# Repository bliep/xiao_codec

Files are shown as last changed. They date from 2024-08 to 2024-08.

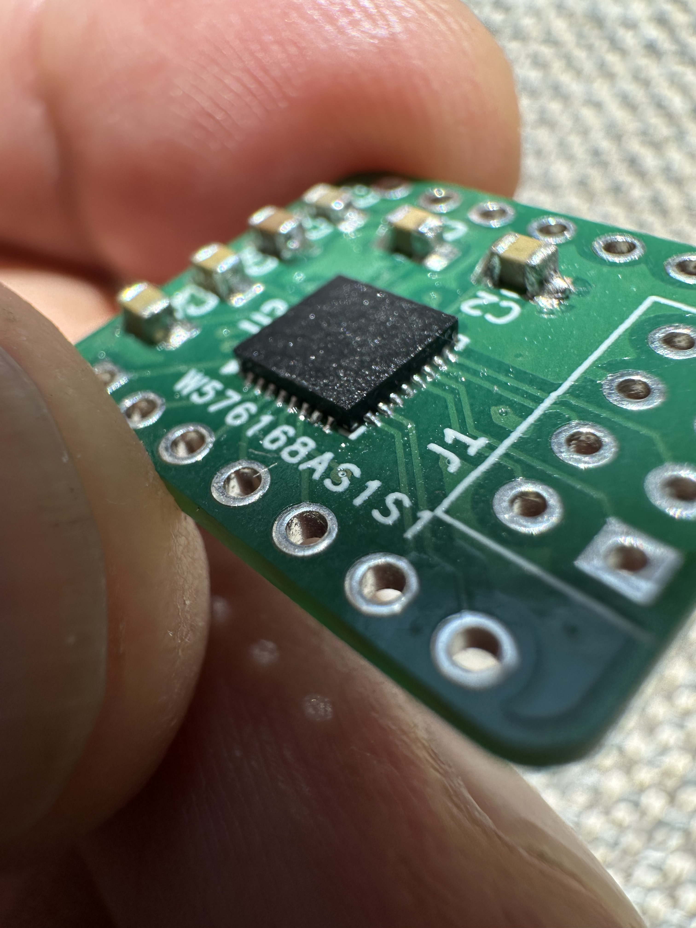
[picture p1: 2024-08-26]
hardware/xiao_codec.jpeg

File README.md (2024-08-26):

# xiao_codec
Audio codec shield for the Seeed xiao-ble (https://wiki.seeedstudio.com/XIAO_BLE/).
The audio codec is a AIC3254 (https://www.ti.com/product/TLV320AIC3254).

# audio IO
The shield has header pins that directly connects to the audio IO pins of the codec. For connecting to headphones or analog microphones see the application note of the codec (https://www.ti.com/lit/ug/slau497a/slau497a.pdf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). I.e. if you want to drive headphones, place series capacitors (47u) on the headphone pins to remove the DC.

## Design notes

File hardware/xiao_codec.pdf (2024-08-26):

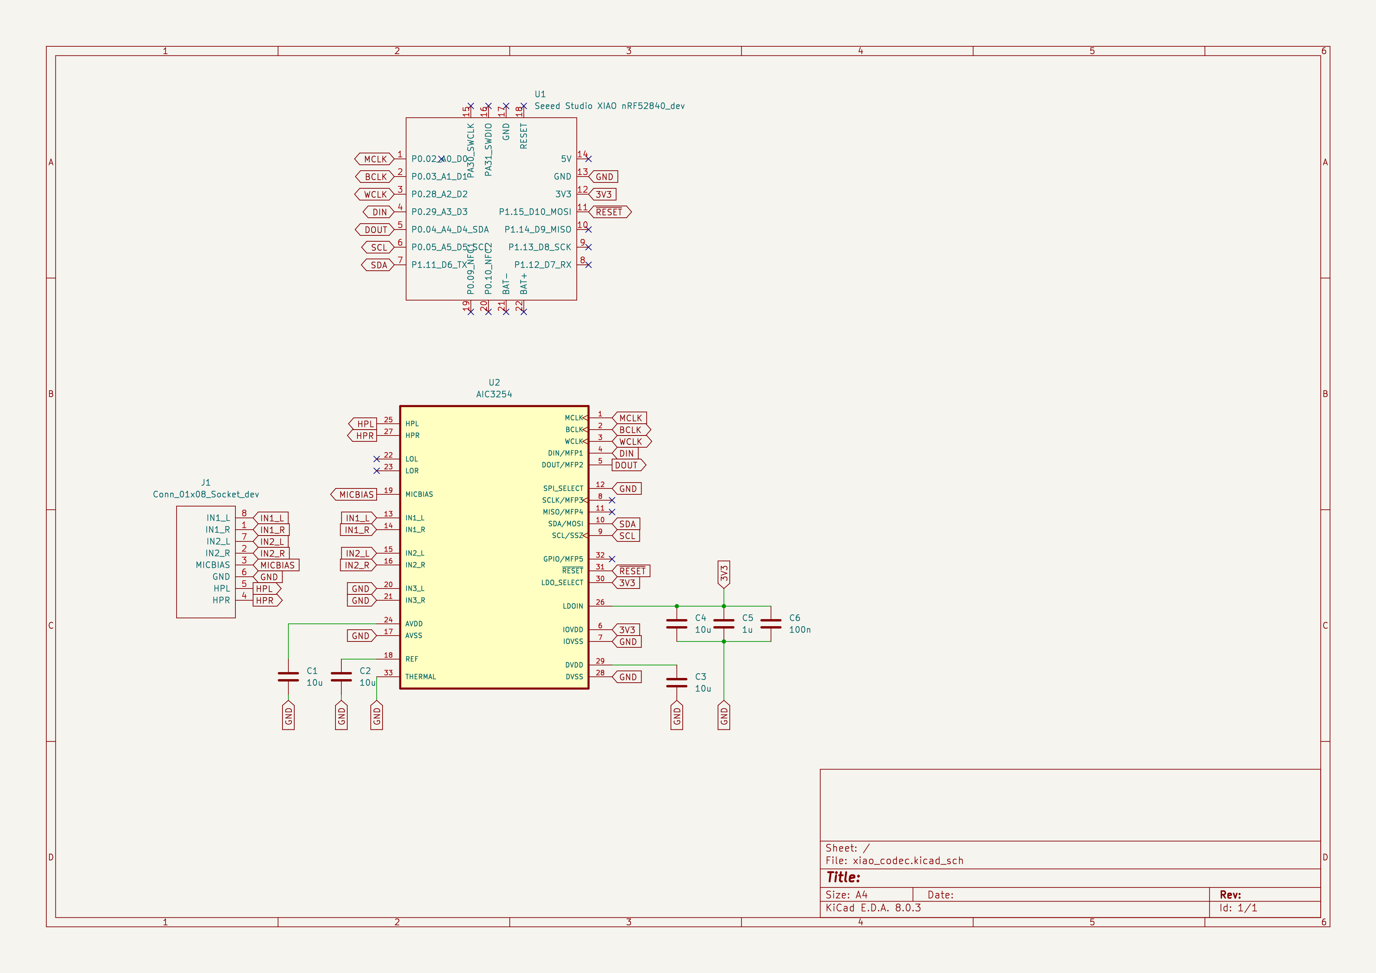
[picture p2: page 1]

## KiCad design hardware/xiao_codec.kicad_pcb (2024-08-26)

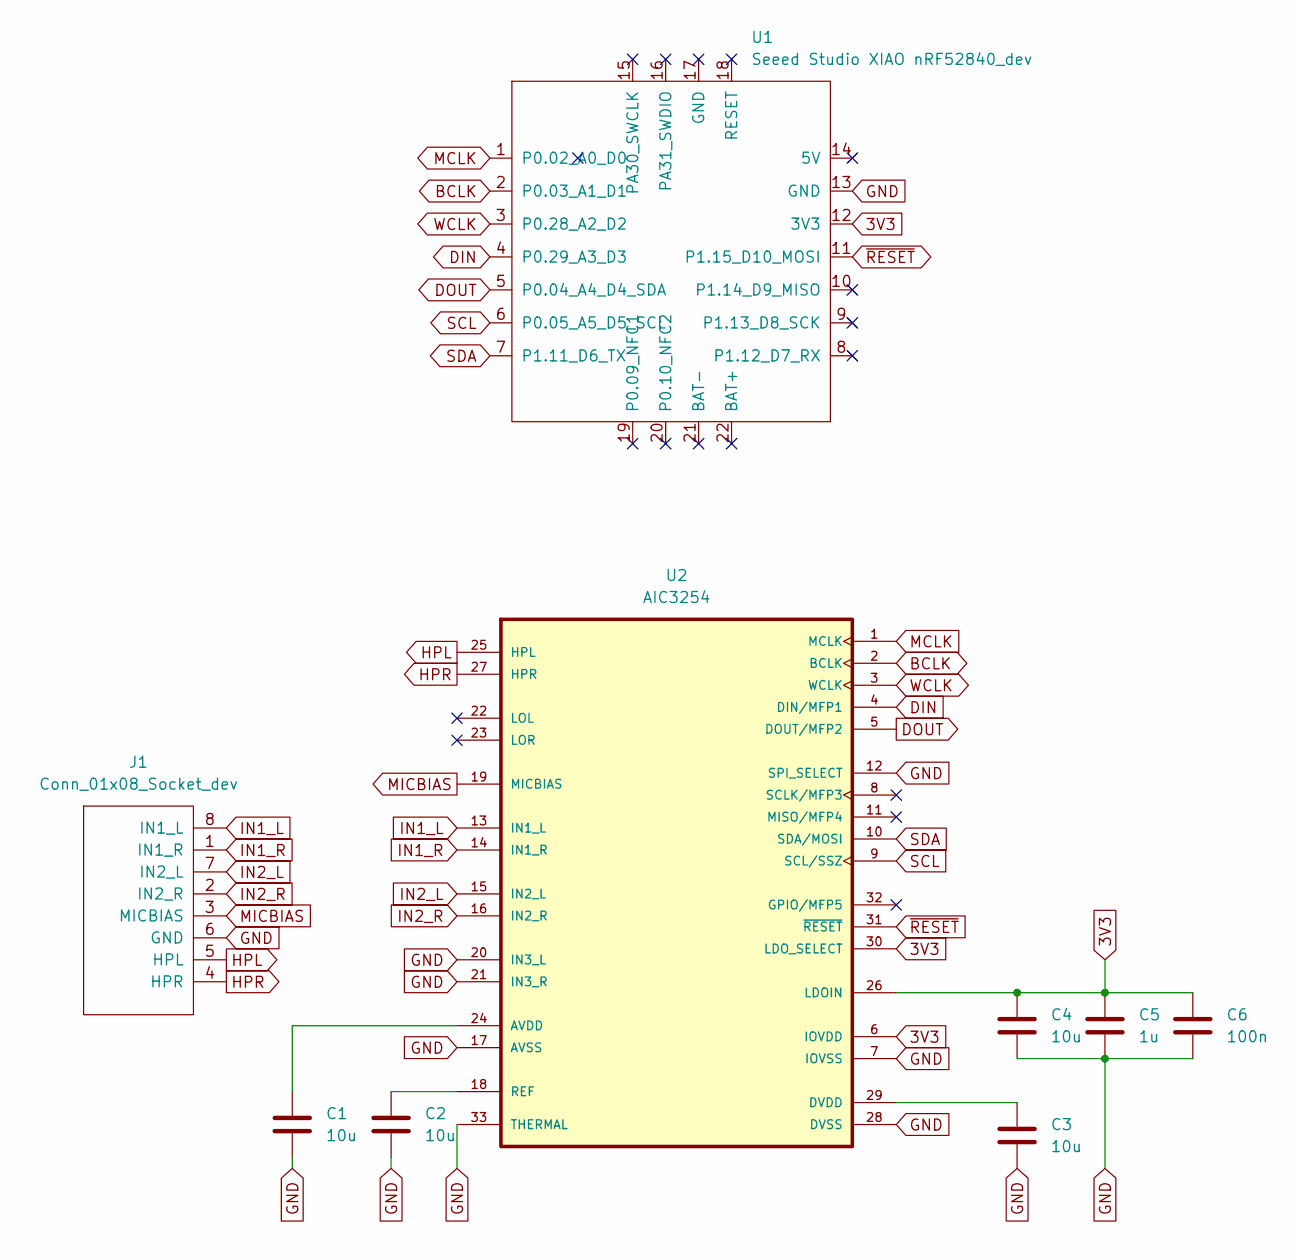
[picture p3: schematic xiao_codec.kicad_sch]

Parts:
C1, C2, C3, C4: 10u; C_0805_2012Metric_Pad1.18x1.45mm_HandSolder
C5: 1u; C_0805_2012Metric_Pad1.18x1.45mm_HandSolder
C6: 100n; C_0805_2012Metric_Pad1.18x1.45mm_HandSolder
J1: Conn_01x08_Socket_dev; Conn_8_dev
U1: Seeed Studio XIAO nRF52840_dev; XIAO-Generic-Thruhole-14P-2.54-21X17.8MM_dev
U2: AIC3254; VQFN-32-1EP_5x5mm_P0.5mm_EP3.1x3.1mm_ThermalVias

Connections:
3V3: C4.2, C5.2, C6.2, U1.12 (3V3), U2.6 (IOVDD), U2.26 (LDOIN), U2.30 (LDO_SELECT)
BCLK: U1.2 (P0.03_A1_D1), U2.2 (BCLK)
DIN: U1.4 (P0.29_A3_D3), U2.4 (DIN/MFP1)
DOUT: U1.5 (P0.04_A4_D4_SDA), U2.5 (DOUT/MFP2)
GND: C1.1, C2.1, C3.1, C4.1, C5.1, C6.1, J1.6 (GND), U1.13 (GND), U2.7 (IOVSS), U2.12 (SPI_SELECT), U2.17 (AVSS), U2.20 (IN3_L), U2.21 (IN3_R), U2.28 (DVSS), U2.33 (THERMAL)
HPL: J1.5 (HPL), U2.25 (HPL)
HPR: J1.4 (HPR), U2.27 (HPR)
IN1_L: J1.8 (IN1_L), U2.13 (IN1_L)
IN1_R: J1.1 (IN1_R), U2.14 (IN1_R)
IN2_L: J1.7 (IN2_L), U2.15 (IN2_L)
IN2_R: J1.2 (IN2_R), U2.16 (IN2_R)
MCLK: U1.1 (P0.02_A0_D0), U2.1 (MCLK)
MICBIAS: J1.3 (MICBIAS), U2.19 (MICBIAS)
unnamed: C1.2, U2.24 (AVDD)
unnamed: C3.2, U2.29 (DVDD)
unnamed: C2.2, U2.18 (REF)
SCL: U1.6 (P0.05_A5_D5_SCL), U2.9 (SCL/SSZ)
SDA: U1.7 (P1.11_D6_TX), U2.10 (SDA/MOSI)
WCLK: U1.3 (P0.28_A2_D2), U2.3 (WCLK)
~RESET: U1.11 (P1.15_D10_MOSI), U2.31 (~RESET)

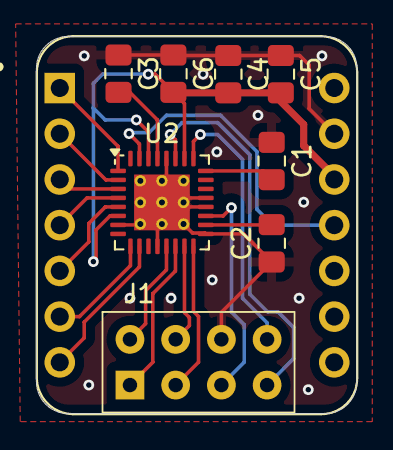
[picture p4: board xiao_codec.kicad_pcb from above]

Board: 2 copper layers, 17.8 x 21.0 mm, 9 parts (0 on the bottom side), 20 nets.

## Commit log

2024-08-26 Schematics and PCB
    [Untitled-B_Cu.gbr, Untitled-B_Mask.gbr, Untitled-B_Paste.gbr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]
2024-08-26 Add schematics PDF
2024-08-26 image of populated PCB
